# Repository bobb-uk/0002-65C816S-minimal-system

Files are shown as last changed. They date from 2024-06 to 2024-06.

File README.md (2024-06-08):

# 0002-65C816S minimal system
This circuit board supports a single WDC 65C816S microprocessor.
It allows attachment to a Digilent Spartan3A Starter Kit via a breakout board (see project [0001](https://github.com/bobb-uk/0001-Spartan3A-FX2-breakout))

The circuit is as basic as it can be.
Only two decoupling capacitors are used, though there are two more empty places incase of decoupling problems.

## Purpose
Purely for fun, to learn Verilog and use the Spartan3A Starter Kit will all its on-board peripherals.

## Board
4 layer FR4.  Top & Bot for signal routing.  Inner 1 & 2 provide GND and Power planes.
See [fabrication PDF](https://github.com/bobb-uk/0002-65C816S-minimal-system/blob/main/Fabrication%20data/0002-65C816S-minimal%20Fabrication%20and%20Assembly.pdf) for layer geometries, silkscreen and assembly.

BOM information, what little there is, can be found in the BOM [folder](https://github.com/bobb-uk/0002-65C816S-minimal-system/tree/main/BOM).

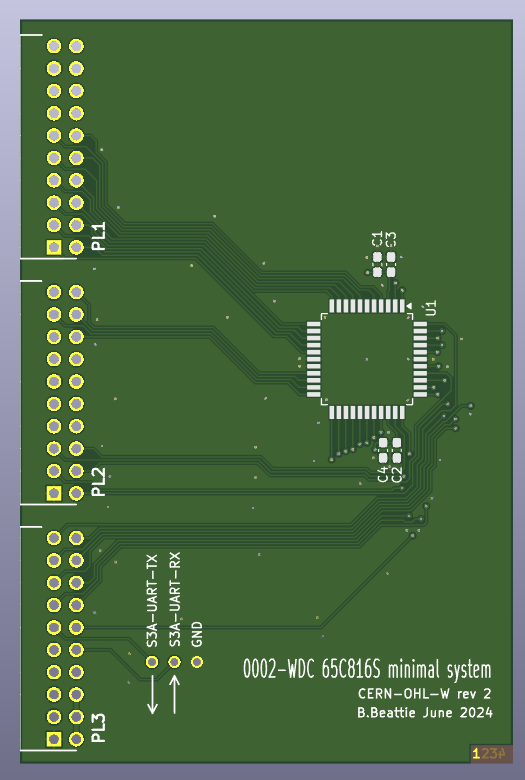
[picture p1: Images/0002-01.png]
blank board

# WDC65C816S
Information in this enhanced version of the 6502 can be found at the [wdc65xx](https://wdc65xx.com/) and [Western Design Center](https://www.westerndesigncenter.com/) websites.

# Revisions
A : 8 June 2024 : CERN-OHL-W rev 2

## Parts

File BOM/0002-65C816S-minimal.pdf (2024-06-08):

0002-65C816S-minimal

Page 1

Project : 0002-65C816S minimal system

Date :

Revision : A

Document : BOM

Designator | Quantity | Manufacturer | Manuf PN | Supplier | Supplier PN | Notes
C2,C1 | 2 | any | | | | size 0603 min 16V
U1 | 1 | WDC | W65C816S6TQG-14 | Mouser | 955-W65C816S6TQG-14
PL2,PL1,PL3 | 3 | Adam-Tech | PH2RA-20-UA | Mouser | 737-PH2RA-20-UA

8

th June 2024

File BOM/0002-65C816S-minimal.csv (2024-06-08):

Id | Designator | Footprint | Quantity | Designation | Supplier and ref
1 | C2,C1 | C_0603_1608Metric_Pad1.08x0.95mm_HandSolder | 2 | 100nF
2 | C4,C3 | C_0603_1608Metric_Pad1.08x0.95mm_HandSolder | 2 | C
3 | U1 | PQFP-44_10x10mm_P0.8mm | 1 | ~
4 | PL2,PL1,PL3 | ADAM-TECH-PH2RA-20-UA | 3 | PH2RA-20-UA

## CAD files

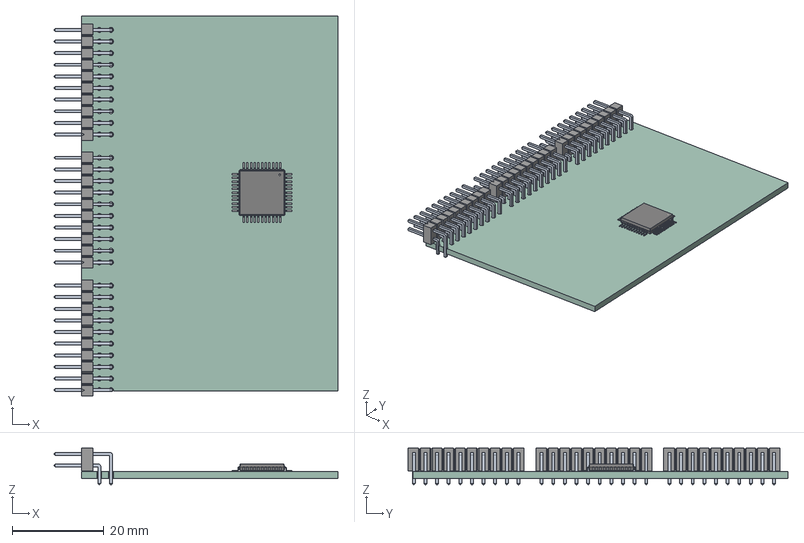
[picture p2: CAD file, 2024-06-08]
0002-65C816S-minimal.step
62.0 x 83.0 x 8.00 mm
PQFP_44_10x10mm_P08mm
ASSEMBLY x 3
0002-65C816S-minimal_PCB

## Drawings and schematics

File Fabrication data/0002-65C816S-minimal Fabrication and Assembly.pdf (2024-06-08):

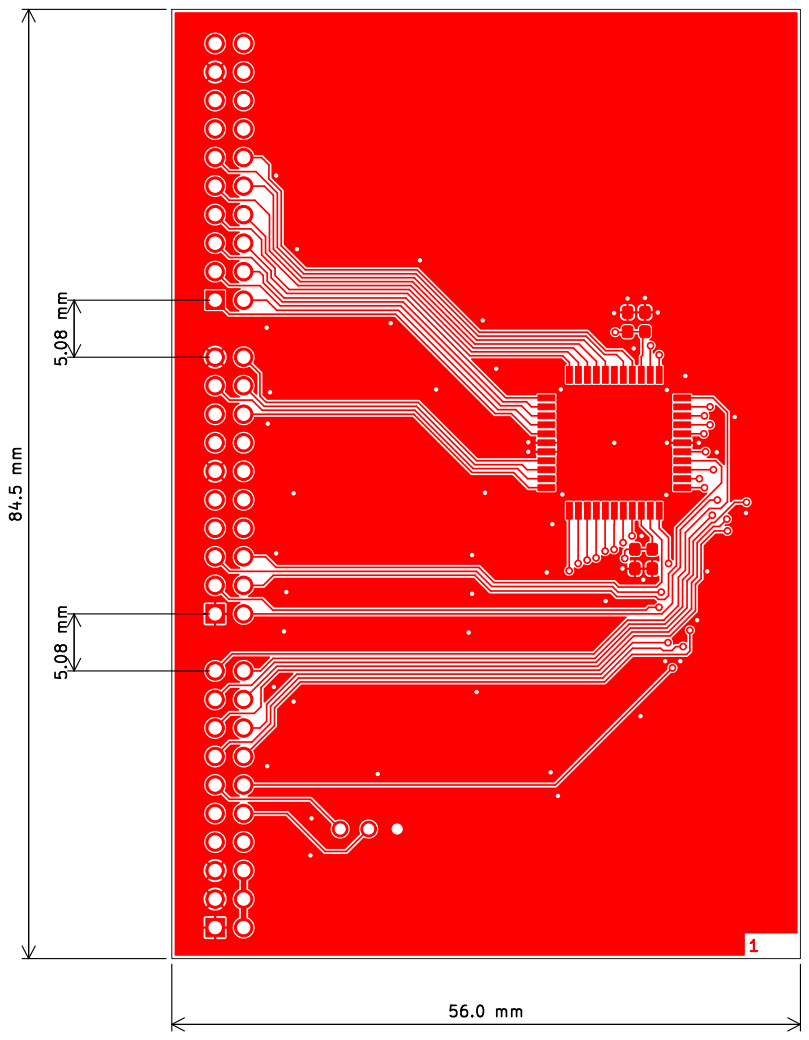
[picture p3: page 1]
D Date: 2024-06-06 KiCad; E.D.A. 8.0.3 Size: A4; Rev: A; Id: 1/1 Title: 65C816S; Minimal System using Spartan3A Starter Kit File: 0002-65C816S-minimal.kicad_pcb Sheet: CERN-OHL-W; ver 2 ⁸⁴.5 mm

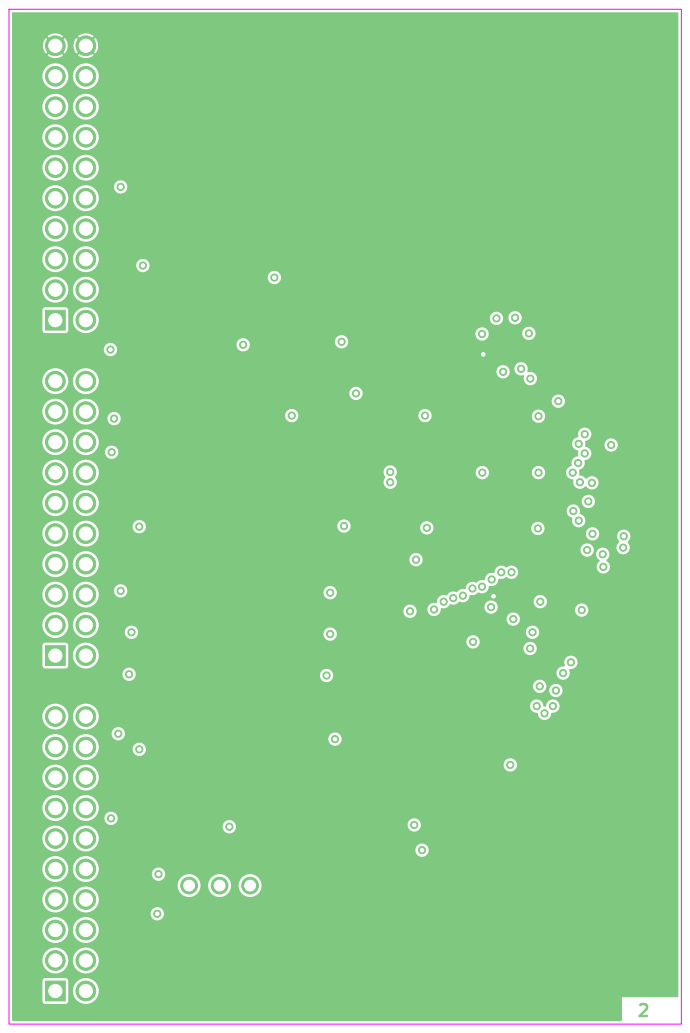
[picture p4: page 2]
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

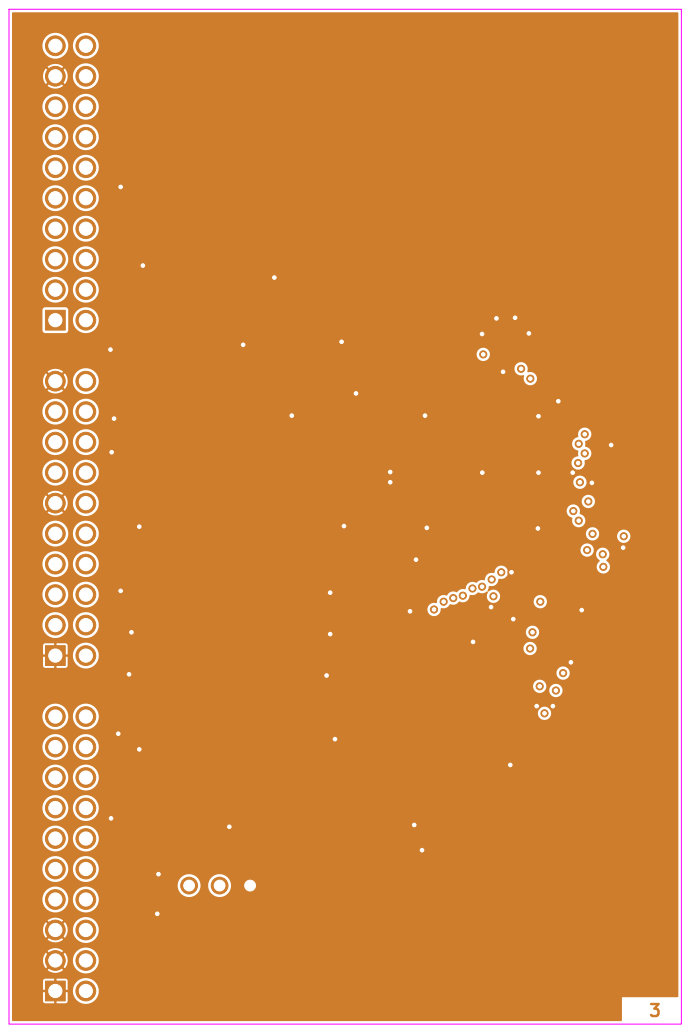
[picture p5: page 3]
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

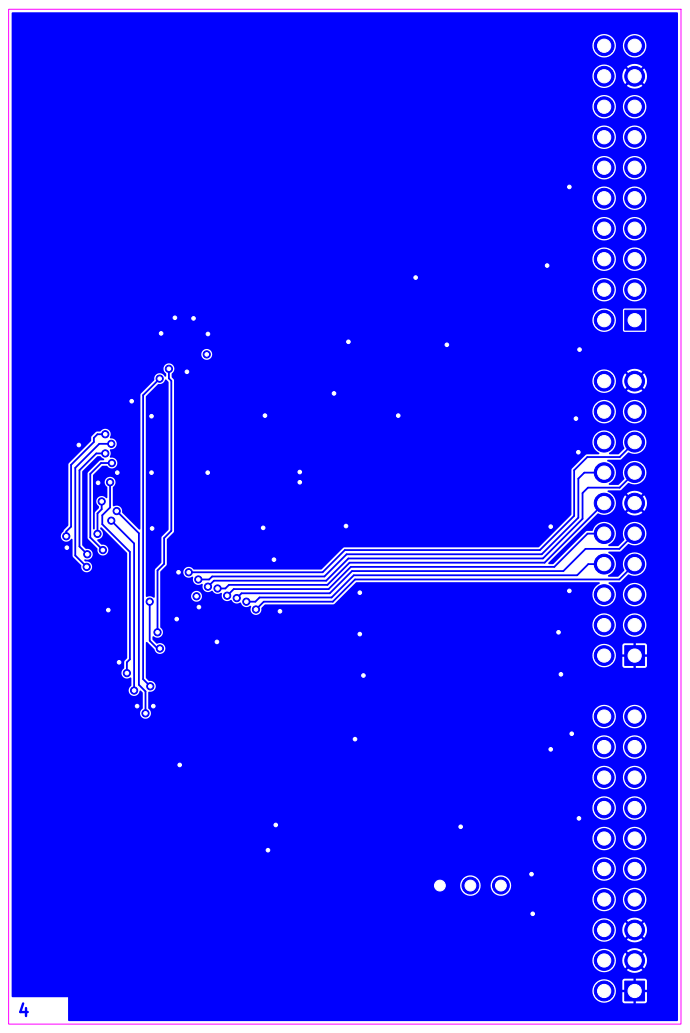
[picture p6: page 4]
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

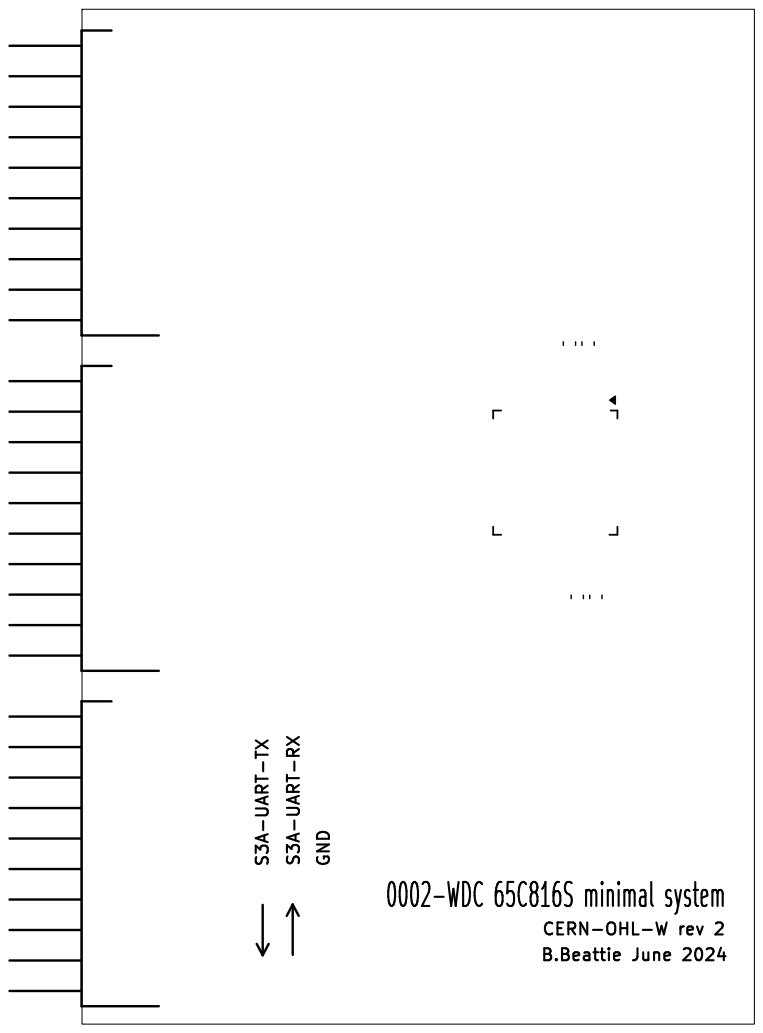
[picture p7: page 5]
0002-WDC; 65C816S minimal; system S³A⁻UART⁻TX; B.Beattie; June 2024 GND; CERN-OHL-W; rev 2 S³A⁻UART⁻RX; D Date: 2024-06-06 KiCad; E.D.A. 8.0.3 Size: A4; Rev: A; Id: 1/1 Title: 65C816S; Minimal System using Spartan3A Starter Kit File: 0002-65C816S-minimal.kicad_pcb Sheet: CERN-OHL-W; ver 2

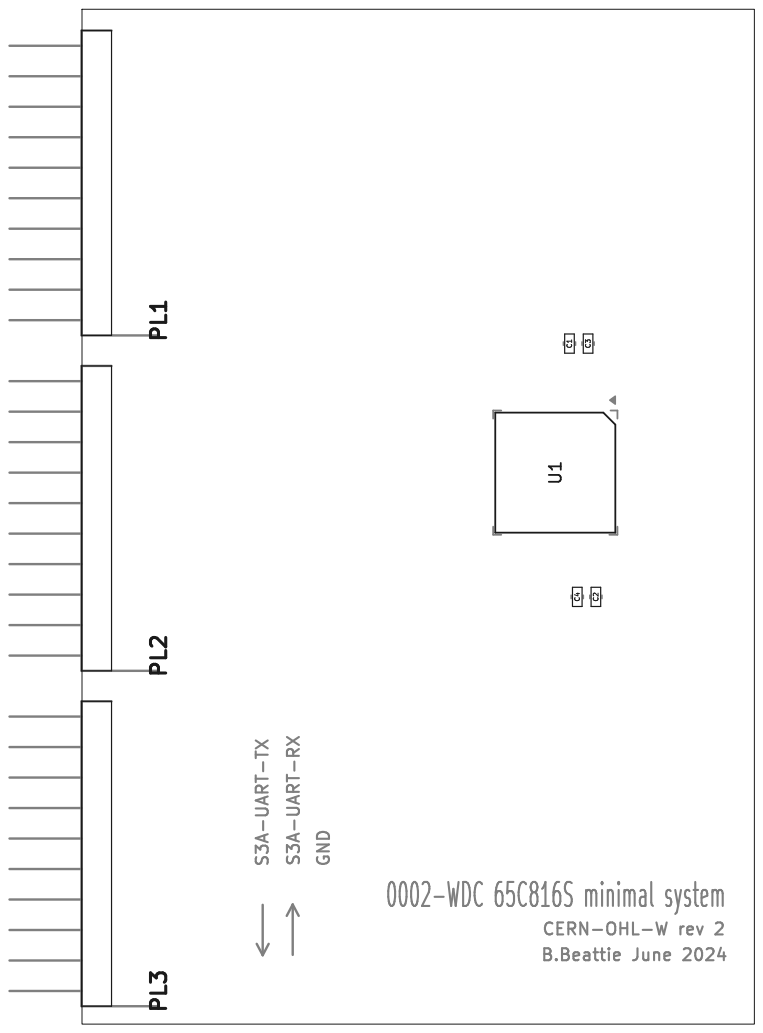
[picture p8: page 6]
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

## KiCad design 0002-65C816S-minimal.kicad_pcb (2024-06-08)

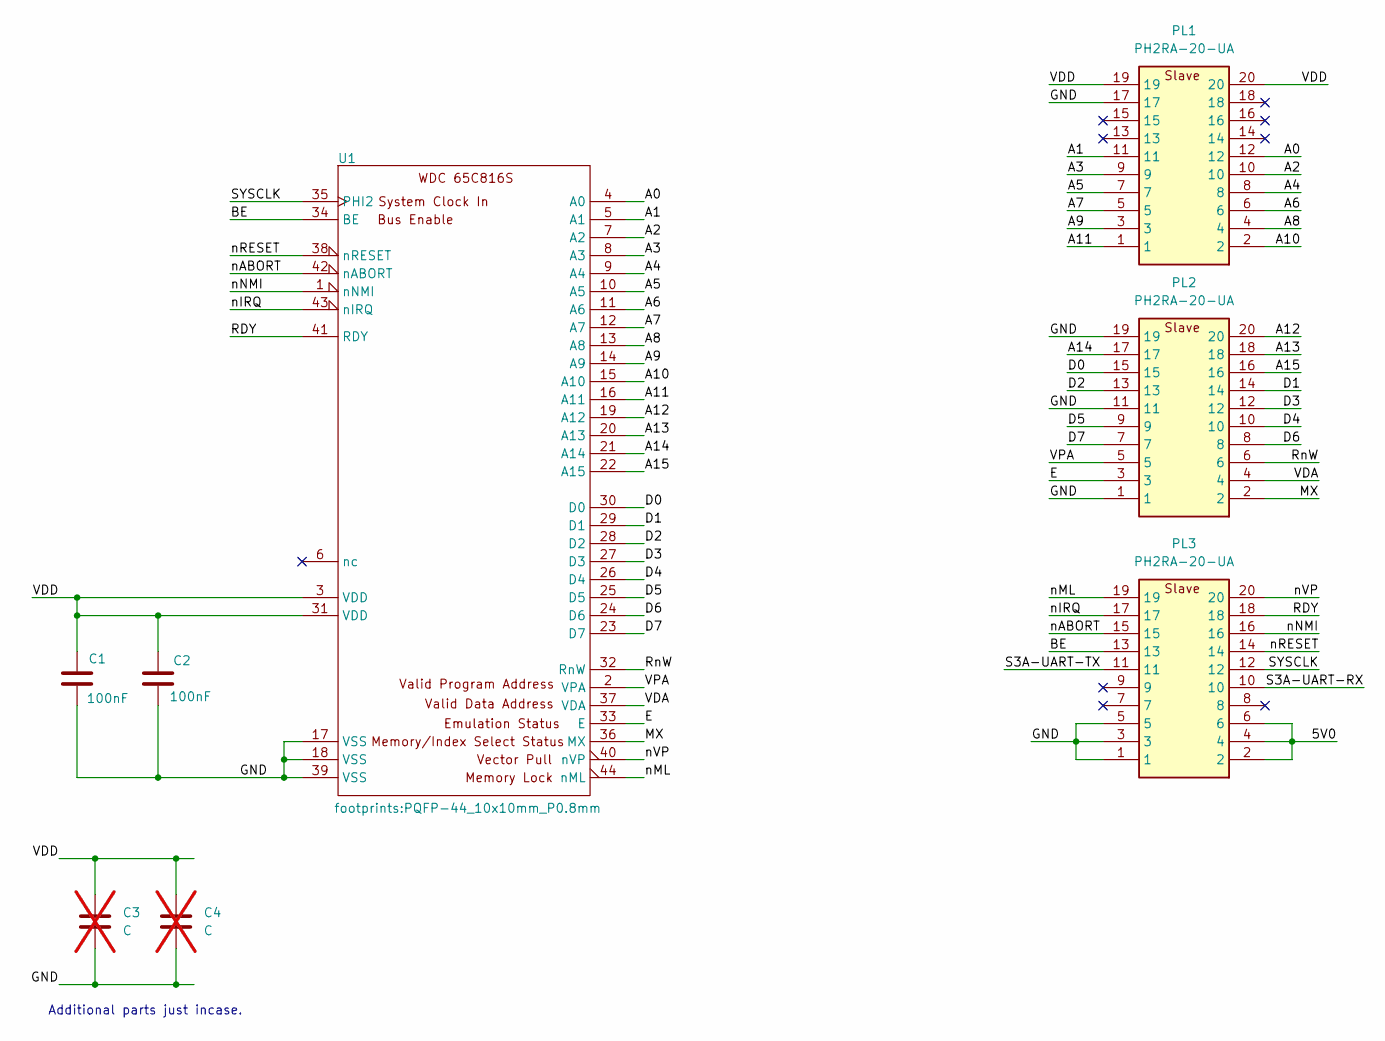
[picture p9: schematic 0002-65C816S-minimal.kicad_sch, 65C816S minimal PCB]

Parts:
C1, C2: 100nF; C_0603_1608Metric_Pad1.08x0.95mm_HandSolder
C3, C4: C; C_0603_1608Metric_Pad1.08x0.95mm_HandSolder; not fitted
PL1, PL2, PL3: PH2RA-20-UA; ADAM-TECH-PH2RA-20-UA; Mouser Part Number 737-PH2RA-20-UA
U1: PQFP-44_10x10mm_P0.8mm

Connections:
/5V0: PL3.2, PL3.4, PL3.6
/A0: PL1.12, U1.4 (A0)
/A1: PL1.11, U1.5 (A1)
/A2: PL1.10, U1.7 (A2)
/A3: PL1.9, U1.8 (A3)
/A4: PL1.8, U1.9 (A4)
/A5: PL1.7, U1.10 (A5)
/A6: PL1.6, U1.11 (A6)
/A7: PL1.5, U1.12 (A7)
/A8: PL1.4, U1.13 (A8)
/A9: PL1.3, U1.14 (A9)
/A10: PL1.2, U1.15 (A10)
/A11: PL1.1, U1.16 (A11)
/A12: PL2.20, U1.19 (A12)
/A13: PL2.18, U1.20 (A13)
/A14: PL2.17, U1.21 (A14)
/A15: PL2.16, U1.22 (A15)
/BE: PL3.13, U1.34 (BE)
/D0: PL2.15, U1.30 (D0)
/D1: PL2.14, U1.29 (D1)
/D2: PL2.13, U1.28 (D2)
/D3: PL2.12, U1.27 (D3)
/D4: PL2.10, U1.26 (D4)
/D5: PL2.9, U1.25 (D5)
/D6: PL2.8, U1.24 (D6)
/D7: PL2.7, U1.23 (D7)
/E: PL2.3, U1.33 (E)
/GND: C1.2, C2.2, C3.2, C4.2, PL1.17, PL2.1, PL2.11, PL2.19, PL3.1, PL3.3, PL3.5, U1.17 (VSS), U1.18 (VSS), U1.39 (VSS)
/MX: PL2.2, U1.36 (MX)
/RDY: PL3.18, U1.41 (RDY)
/RnW: PL2.6, U1.32 (RnW)
/S3A-UART-RX: PL3.10
/S3A-UART-TX: PL3.11
/SYSCLK: PL3.12, U1.35 (PHI2)
/VDA: PL2.4, U1.37 (VDA)
/VDD: C1.1, C2.1, C3.1, C4.1, PL1.19, PL1.20, U1.3 (VDD), U1.31 (VDD)
/VPA: PL2.5, U1.2 (VPA)
/nABORT: PL3.15, U1.42 (nABORT)
/nIRQ: PL3.17, U1.43 (nIRQ)
/nML: PL3.19, U1.44 (nML)
/nNMI: PL3.16, U1.1 (nNMI)
/nRESET: PL3.14, U1.38 (nRESET)
/nVP: PL3.20, U1.40 (nVP)

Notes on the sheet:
Additional parts just incase.

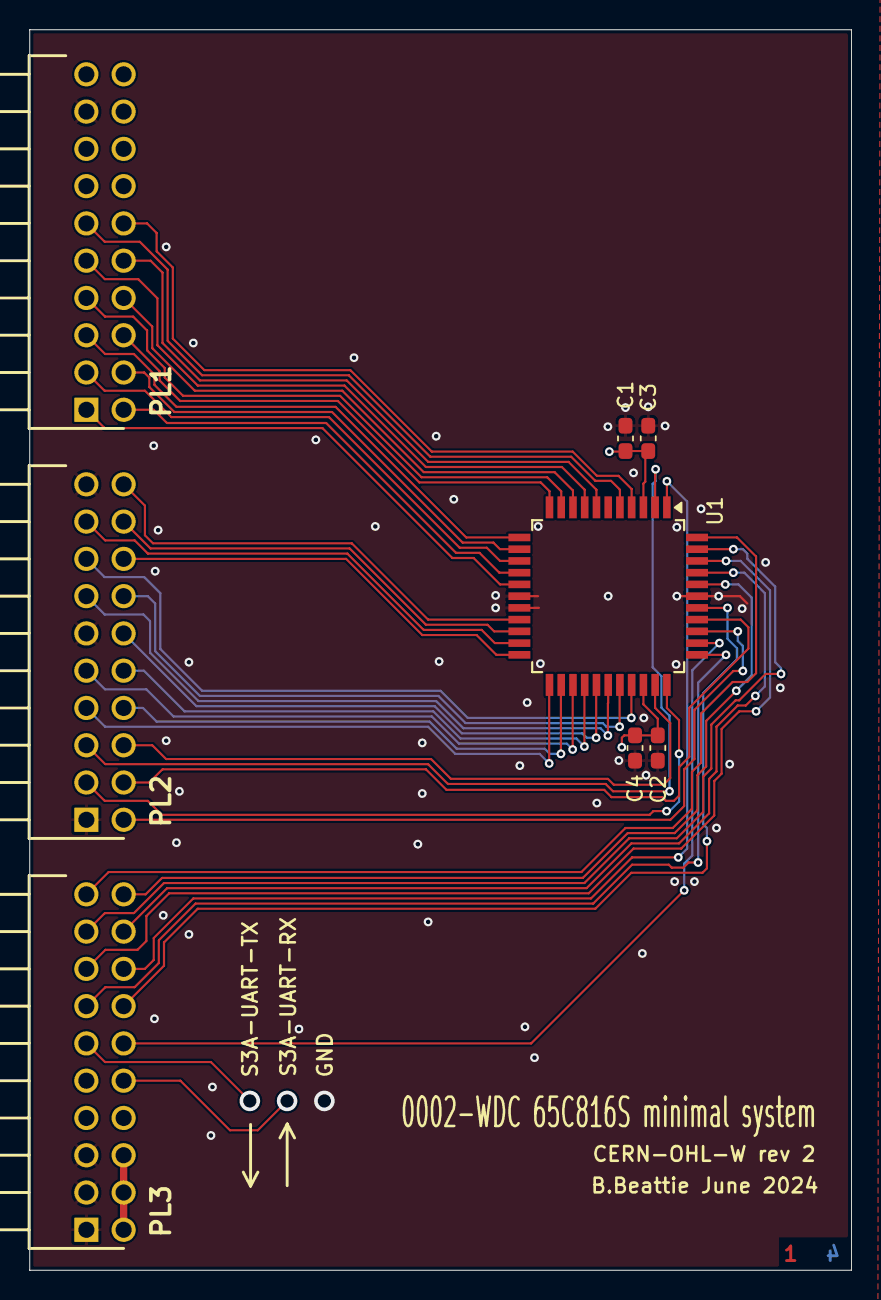
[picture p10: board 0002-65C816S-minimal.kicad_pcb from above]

Board: 4 copper layers, 56.0 x 84.5 mm, 8 parts (0 on the bottom side), 41 nets.
